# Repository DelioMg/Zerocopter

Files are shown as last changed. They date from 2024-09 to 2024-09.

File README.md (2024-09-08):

#  Sistema de Controle de Voo com Raspberry Pi Zero 2W

## Visão Geral

Este projeto tem como objetivo o desenvolvimento de um sistema de controle de voo usando o **Raspberry Pi Zero 2W** e diversos sensores e controladores acoplados para fornecer estabilidade e navegação autônoma a drones.

## Versão 1 (V1)

Na versão inicial do projeto, a configuração inclui:
- **Placa Base** acoplada ao **Raspberry Pi Zero 2W**
- **Câmera** conectada à entrada **MIPI-CSI**
- Sensores integrados:
  - **IMU MPU9250** (sensor de movimento)
  - **Sensor de pressão MS5611**
  - **Conversor ADC ADS1115** para leitura de sinais analógicos
- **Controlador de motores**:
  - A placa possui saídas para conexão direta aos ESCs dos motores
  - A alimentação dos motores é feita por uma bateria **2S**
  - Um **regulador stepdown** de 5V é utilizado para alimentar o Raspberry Pi

Toda a lógica de controle do voo, incluindo a estabilização e processamento dos dados dos sensores, é realizada pelo **Raspberry Pi Zero 2W**.
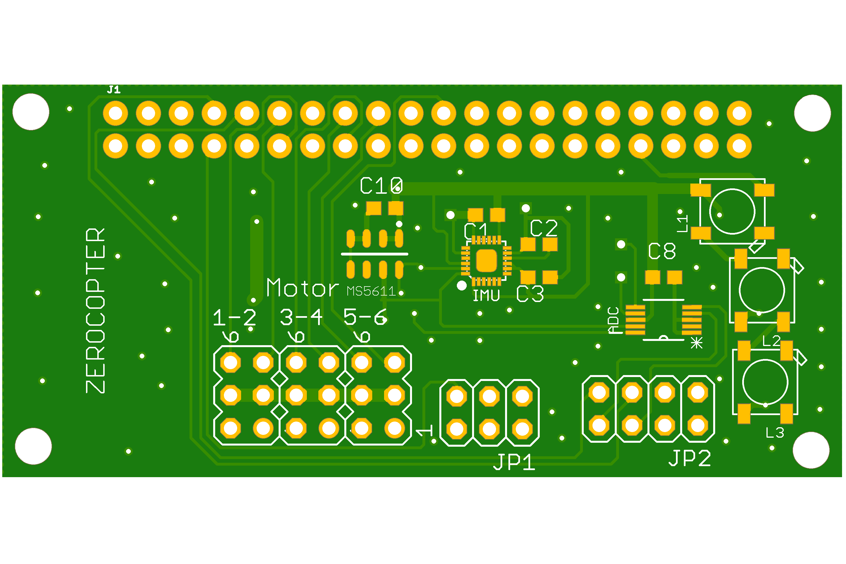
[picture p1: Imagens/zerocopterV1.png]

## Versão 2 (V2)

Na segunda versão do projeto, foram realizadas melhorias significativas para otimizar a estabilidade e o desempenho do sistema:
- Foi adicionado um **microcontrolador RP2040** para gerenciar o controle dos motores e garantir maior precisão na estabilidade do voo
- Um módulo **GPS** foi adicionado ao Raspberry Pi para fornecer dados de localização e permitir a navegação autônoma

## Estrutura do Projeto

- **Hardware**: Raspberry Pi Zero 2W, RP2040, MPU9250, MS5611, ADS1115, regulador stepdown 5V, bateria 2S, câmera, GPS.
- **Software**: Controle de voo implementado no Raspberry Pi Zero 2W (V1), com suporte para integração do RP2040 no controle dos motores (V2).

## Instruções de Uso

1. Clone este repositório:
    ```bash
    git clone https://github.com/DelioMg/Zerocopter.git
    ```
2. Monte a placa base e conecte os componentes de acordo com o diagrama de hardware.
3. Instale as dependências necessárias para o Raspberry Pi Zero 2W e os sensores conectados.
4. Execute o código no Raspberry Pi para iniciar o sistema de controle de voo.

## Melhorias Futuras

- Integração com mais sensores de navegação
- Otimização do tempo de resposta do RP2040 no controle dos motores

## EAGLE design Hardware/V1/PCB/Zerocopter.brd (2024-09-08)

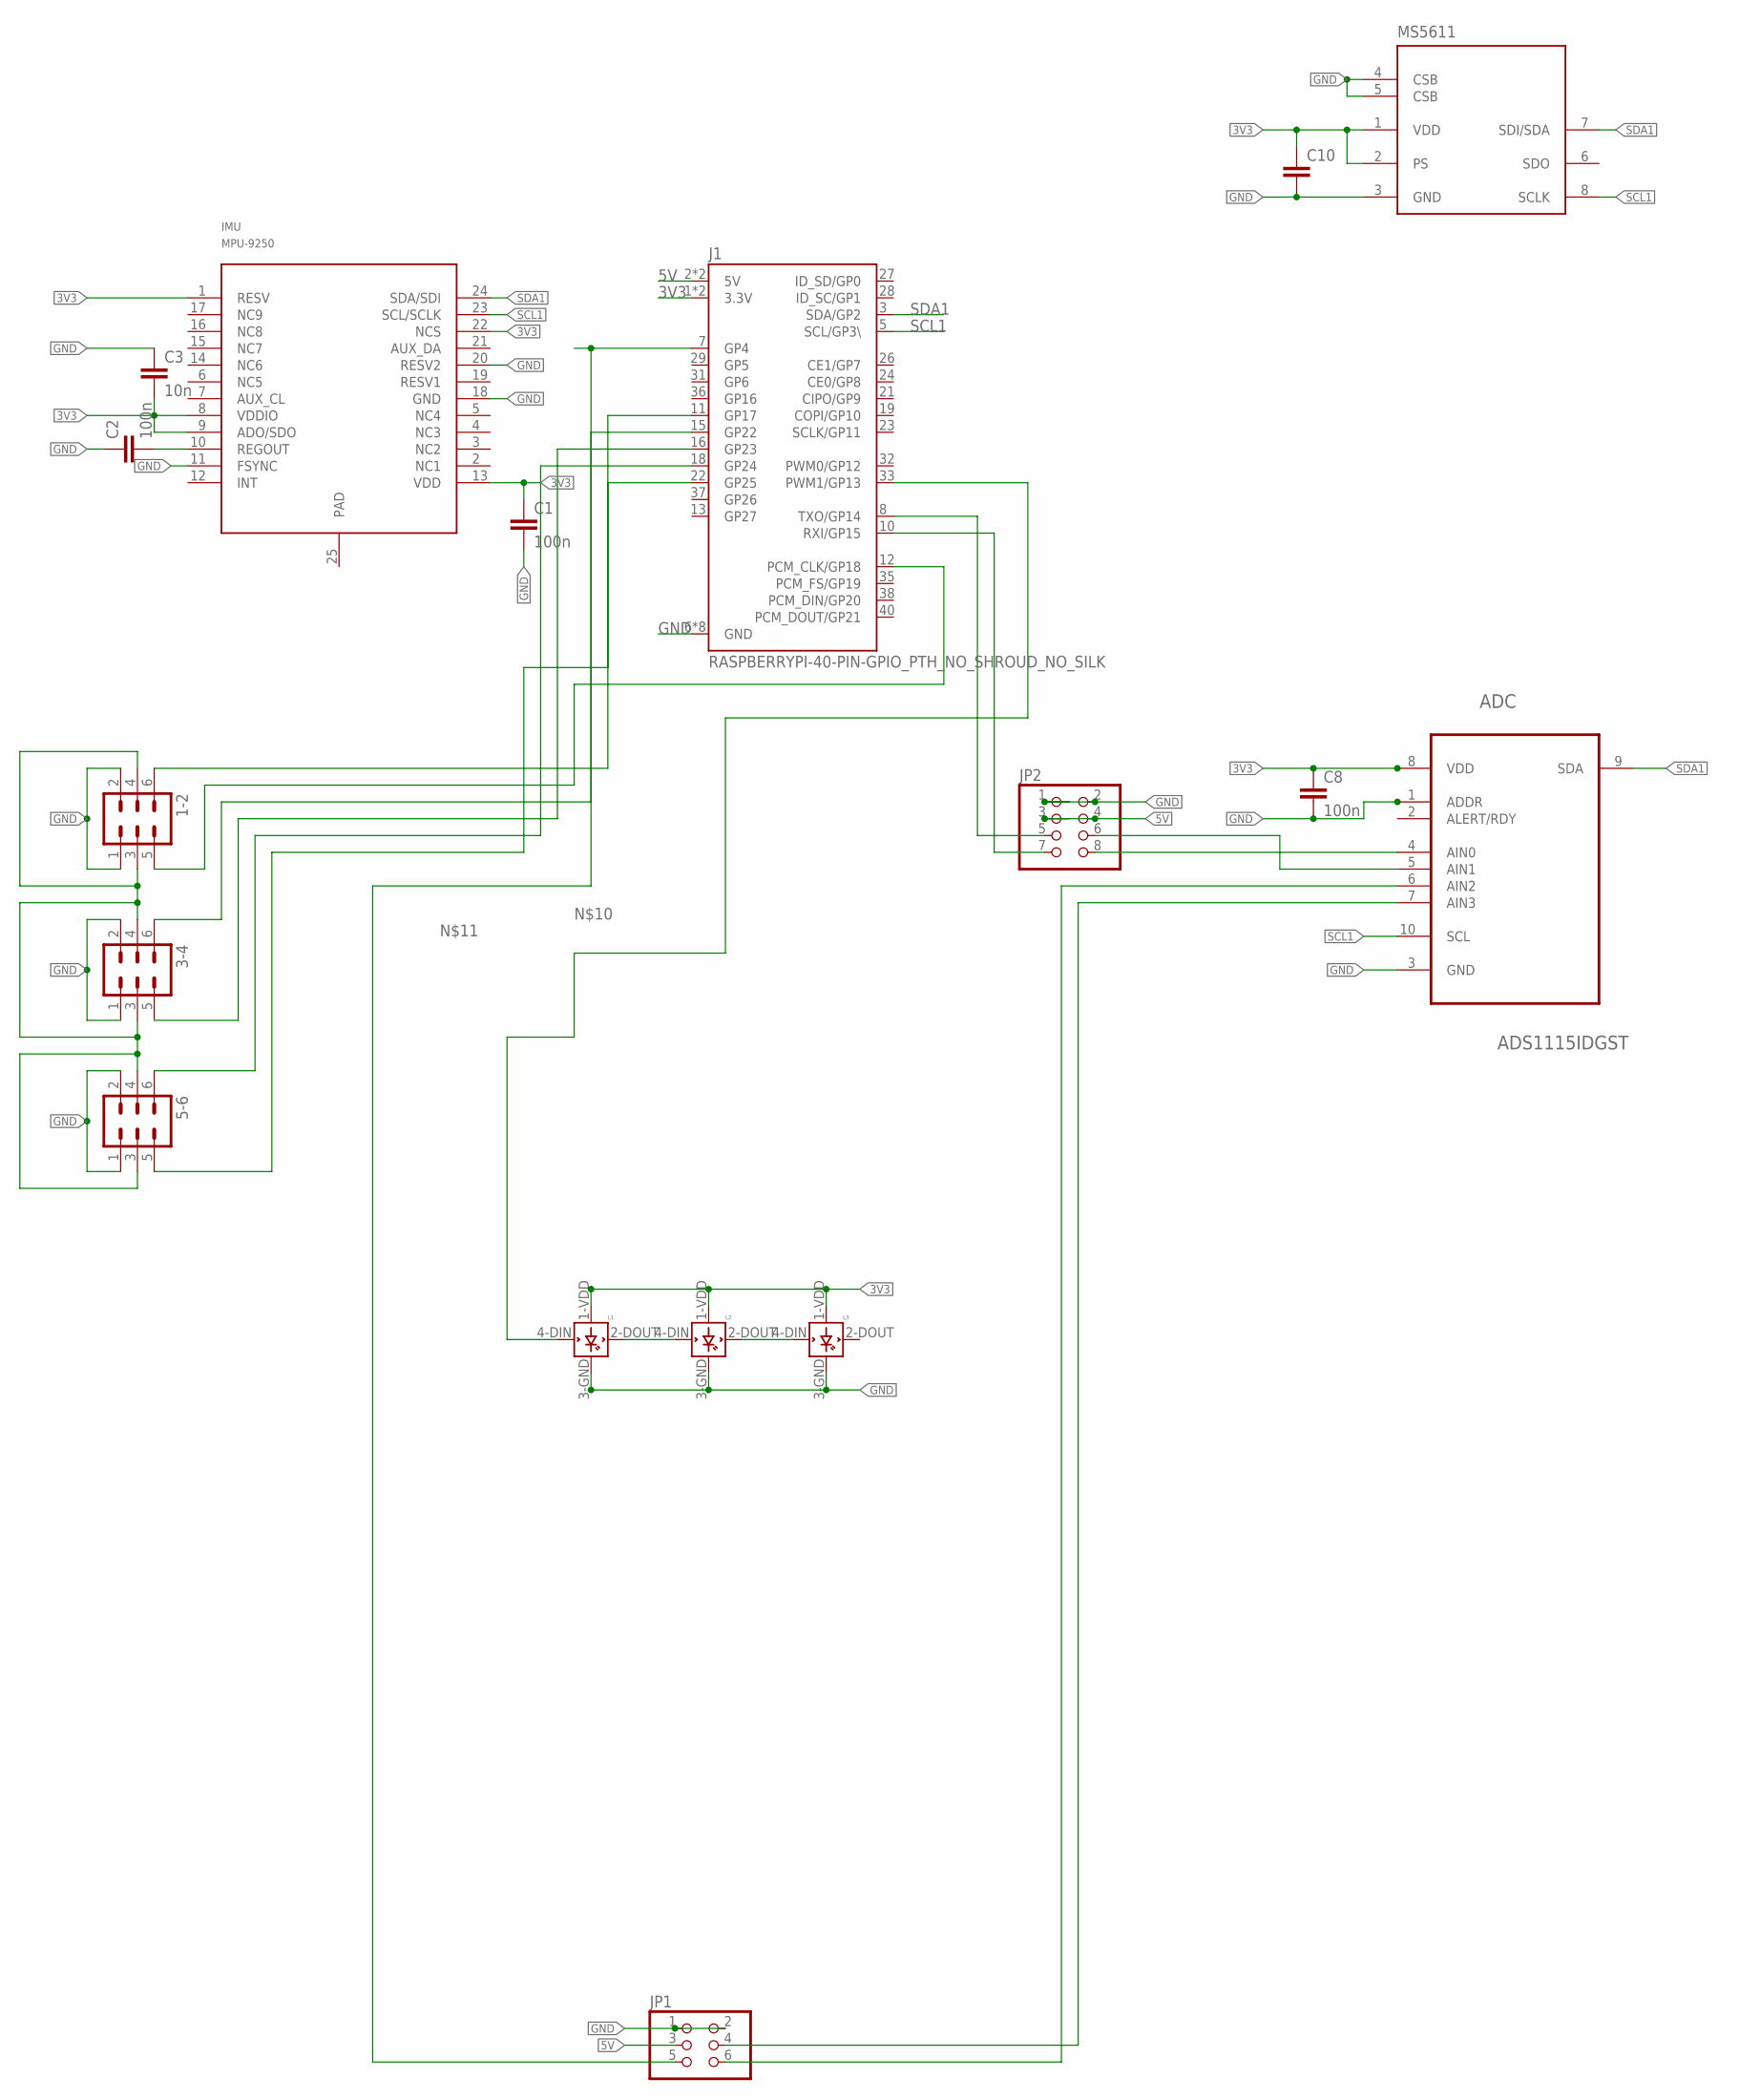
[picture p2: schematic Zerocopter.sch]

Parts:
1-2, 3-4, 5-6: MA03-2
ADC: ADS1115IDGST; SOP50P490X110-10N
C1, C2, C8: 100n; C0603
C3: 10n; C0603
C10: C-EUC0603; C0603
IMU: MPU-9250; LEAD-QFN24
J1: RASPBERRYPI-40-PIN-GPIO_PTH_NO_SHROUD_NO_SILK; 2X20_NOSILK
JP1: PINHD-2X3; 2X03
JP2: PINHD-2X4; 2X04
L1, L2, L3: WS2812B
MS5611: MS5611-01BA03; SON125P300X500X100-8N

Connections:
3V3: ADC.8 (VDD), C1.1, C3.2, C8.1, C10.1, IMU.1 (RESV), IMU.8 (VDDIO), IMU.9 (ADO/SDO), IMU.13 (VDD), IMU.22 (NCS), J1.1 (3.3V), J1.17 (3.3V), L1.1-VDD (VDD), L2.1-VDD (VDD), L3.1-VDD (VDD), MS5611.1 (VDD), MS5611.2 (PS)
5V: J1.2 (5V), J1.4 (5V), JP1.3, JP2.3, JP2.4
GND: 1-2.1, 1-2.2, 3-4.1, 3-4.2, 5-6.1, 5-6.2, ADC.1 (ADDR), ADC.3 (GND), C1.2, C2.1, C3.1, C8.2, C10.2, IMU.11 (FSYNC), IMU.18 (GND), IMU.20 (RESV2), J1.6 (GND), J1.9 (GND), J1.14 (GND), J1.20 (GND), J1.25 (GND), J1.30 (GND), J1.34 (GND), J1.39 (GND), JP1.1, JP1.2, JP2.1, JP2.2, L1.3-GND (GND), L2.3-GND (GND), L3.3-GND (GND), MS5611.3 (GND), MS5611.4 (CSB), MS5611.5 (CSB)
unnamed: C2.2, IMU.10 (REGOUT)
unnamed: J1.8 (TXO/GP14), JP2.5
unnamed: L1.2-DOUT (DOUT), L2.4-DIN (DIN)
unnamed: L2.2-DOUT (DOUT), L3.4-DIN (DIN)
unnamed: ADC.6 (AIN2), JP1.6
unnamed: ADC.7 (AIN3), JP1.4
unnamed: 1-2.6, J1.11 (GP17)
unnamed: 1-2.5, J1.12 (PCM_CLK/GP18)
unnamed: J1.33 (PWM1/GP13), L1.4-DIN (DIN)
unnamed: J1.7 (GP4), JP1.5
unnamed: ADC.5 (AIN1), JP2.6
unnamed: 3-4.6, J1.15 (GP22)
unnamed: 3-4.5, J1.16 (GP23)
unnamed: 5-6.6, J1.18 (GP24)
unnamed: 5-6.5, J1.22 (GP25)
unnamed: ADC.4 (AIN0), JP2.8
unnamed: J1.10 (RXI/GP15), JP2.7
unnamed: 1-2.3, 1-2.4, 3-4.3, 3-4.4, 5-6.3, 5-6.4
SCL1: ADC.10 (SCL), IMU.23 (SCL/SCLK), J1.5 (SCL/GP3\), MS5611.8 (SCLK)
SDA1: ADC.9 (SDA), IMU.24 (SDA/SDI), J1.3 (SDA/GP2), MS5611.7 (SDI/SDA)

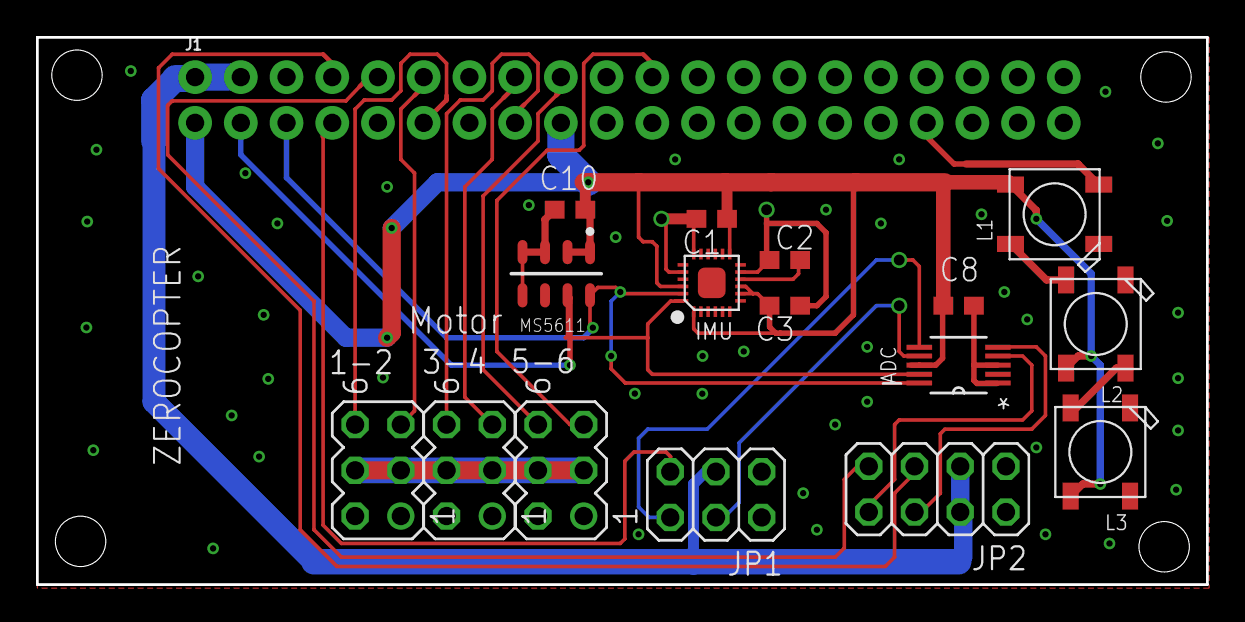
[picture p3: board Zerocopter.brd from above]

Board: 2 copper layers, 65.0 x 30.4 mm, 17 parts (0 on the bottom side), 23 nets.

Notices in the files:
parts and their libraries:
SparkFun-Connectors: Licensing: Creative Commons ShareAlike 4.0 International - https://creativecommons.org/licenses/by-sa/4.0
